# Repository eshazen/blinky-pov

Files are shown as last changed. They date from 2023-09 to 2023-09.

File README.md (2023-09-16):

# Blinky POV

This is a copy of designs from the EDF SVN for Blinky POV (persistence
of vision) toys for soldering training and outreach.

**AVR4** - Version 4 of thru-hole design using an ATTiny44A MCU.
This includes firmware and HTML blinky programming code

**BlinkyColorPOV** - Version using RGB LEDs.  Some issues with
soldering the 4-pin LEDs.  Probably overly-complex for a new project.

See https://github.com/eshazen/blinky-avr-smt for a newer version
based loosely on AVR4.

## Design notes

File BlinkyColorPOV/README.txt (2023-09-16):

This repository contains the documentation and firmware for the "Blinky Color POV"
gadget, which displays text in color when waved back and forth in the air.

Downloading is accomplished using a variation of the "Blinky POV" optical download
technique by Wayne&Layne.  See: http://www.wayneandlayne.com/projects/blinky/

Hardware  	       KiCAD PCB layout and gerber files
		       Hardware/gerber/blinky_color2.zip is latest fab package

Firmware/ColorText     Firmware for final version
		       Edit makefile as required for download cable, then
		       'make fuse' and 'make flash'

Programming	       Javascript download tool
		       use 'colortext.html', with on-screen documentation

myFont2c	       Contains 'fontExtract' tool which converts an X11 bitmap
		       font to javascript data

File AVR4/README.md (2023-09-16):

# blinky-pov
Blinky POV soldering projects

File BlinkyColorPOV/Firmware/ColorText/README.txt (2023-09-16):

First attempt at full version.
Character-based, ASCII codes 32-95 supported

Timing issues:

Optimized I2C for accel- 400kHz clock, read only one byte (X)
A read takes about 130us.  Could be interrupt driven?

Neopixel timing is 24 bits '1' is 1.5uS, '0' is 1.3uS.
So 1.5uS * 24 * 8 is about 300uS for an update of all 8 LEDs

Hand sweep of blinky is ~ 1Hz or 500ms per direction.
If we allow 20 characters at average with of 5 pixels, that's
100 pixels or 5ms per pixel.  Should work down to 1ms per pixel,
For total error less than 1/2 character (2 pixels) that's
2% of 5ms or 100us.  So pixel timing should be scheduled in 
100uS ticks.

Interrupts must be disabled during neopixel output, though
the timer can still run.

Timer setup for non-interrupt ops:
TCCR1A = $00
TCCR1B = $0x where x is $04 with prescale 1...5 for 1, 8, 64...1024

Proposed implementation:

Setup timer1 for 128uS counting (prescale=1024)

Measure time between zero-crossings (200-700ms or so)
Calculate pixel update period in 100us uinits.

100us loop:
  if time >= next_pixel:
    run_pixel_update
  if time >= next_accel:
    run_accel_update

----------------------------------------

Download protocol:

9 bit tokens
  0x55 0x1aa        (sync)
  <nchars>          (character count)
  <code> <code>..   (low 6 bits are character code, upper 3 are color)
  <checksum>        (such that sum of all = 0)

Character codes start with 0=ascii 32 (space), 1=ascii 33 "!" etc
through 63=ascii 95 (unused code)

Sent as DDR bit-stream as follows using blinking squares on monitor.
Maximum achievable rate with a typical browser/monitor seems to
be about 10 bits/s.

white    +----+    +----+    +----+    +----+    +----+    +----+    
CLOCK    |    |    |    |    |    |    |    |    |    |    |    | 
black----+    +----+    +----+    +----+    +----+    +----+    +--

white  +----+    +----+    +----+    +----+    +----+    +----+    
DATA   | 8  | 7  | 6  | 5  | 4  | 3  | 2  | 1  | 0  | 8  | 7  | 6  
black--+    +----+    +----+    +----+    +----+    +----+    +----

One thing to note is that since the transfer is DDR and the word
length is odd, that the first word's MSB is on a rising clock edge,
while next is on a falling clock edge etc.

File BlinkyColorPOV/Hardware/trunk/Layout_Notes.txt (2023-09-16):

10/24/17  Edits for 2017

* Stagger pins on LEDs for easier soldering
  with bigger pads/holes

Check on below, not sure all done

*  Polarity mark on IC1
*  SW2 holes too small
*  Move P1 up a bit
*  Fix light sensor wiring:  GND bottom, ADC to middle, now ADC is good
*  USART works Tx and Rx

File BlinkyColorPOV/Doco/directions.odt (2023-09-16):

Blinky Color POV Parts rev 2

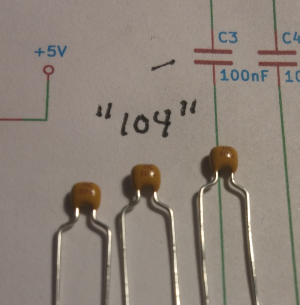
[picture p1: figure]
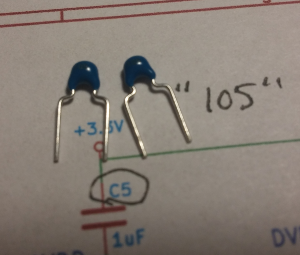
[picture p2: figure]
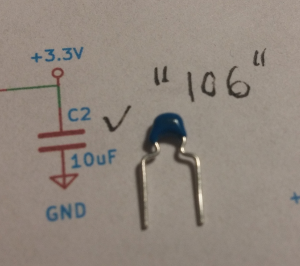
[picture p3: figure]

100nF Capacitor (C1, C3, C4, C6) | 1uF Capacitor( C5, C7, C8) marked “105” in tiny print Need 3 of these | 10uF Capacitor (C2) marked “106” in tiny print With a black dot

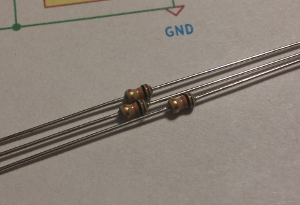
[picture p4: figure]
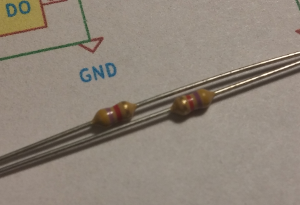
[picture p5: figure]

10k Resistor (R1, R4, R5) | 4.7k Resistor (R2, R3) | LED (D1-D8)

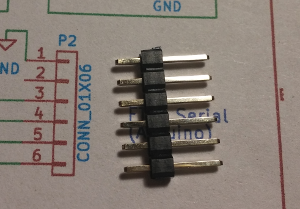
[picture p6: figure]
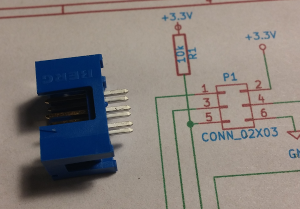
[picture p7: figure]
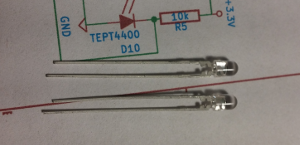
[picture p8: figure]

Connector (Optional) P2 | Connector (Optional) P1 | Light sensors (D9, D10)

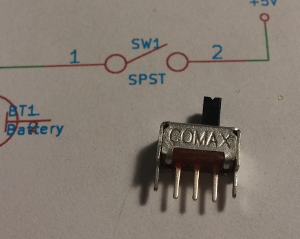
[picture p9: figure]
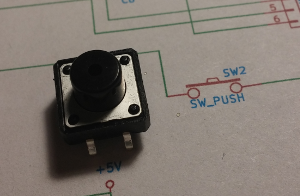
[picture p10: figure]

Switch (SW1) | Push button (SW2) | Voltage regulator (U1)

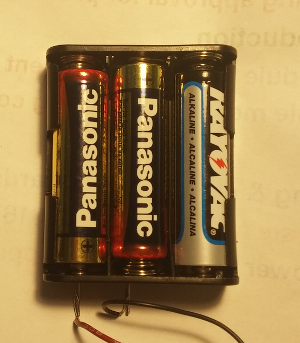
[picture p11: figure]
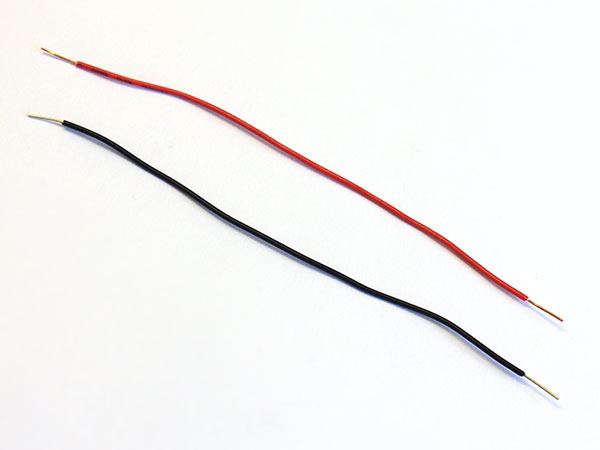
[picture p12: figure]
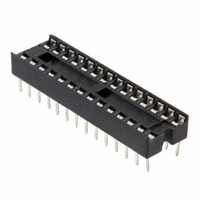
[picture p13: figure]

Battery Case | Red and Black Wires | IC Socket

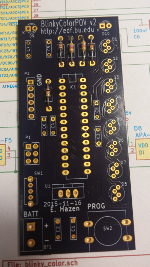
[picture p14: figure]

Circuit Board

# Directions.....

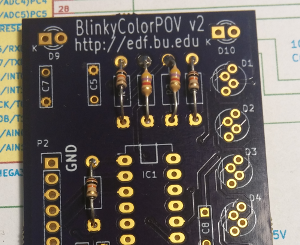
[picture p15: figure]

1. Solder in the resistors R2 and R3 are 4.7k Yellow, Violet, Red, Gold R1, R4 and R5 are 10k Brown, Black, Orange, Gold

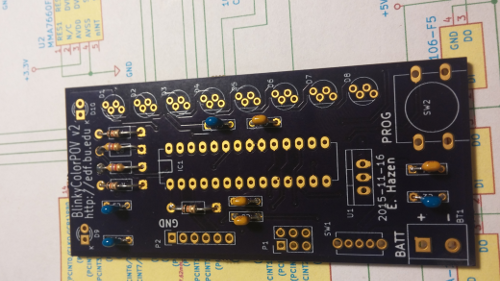
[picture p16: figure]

2. Solder in the capacitors C2 is 10uF “106” C5, C7, C8 are 1uF “105” C1, C3, C4, C6 are 0.1uF “104”

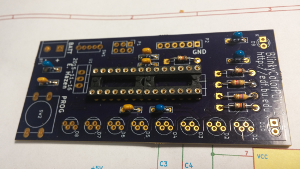
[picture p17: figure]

3. Solder in the IC socket IC1 Be sure the notch is the same way up as the mark on the board!

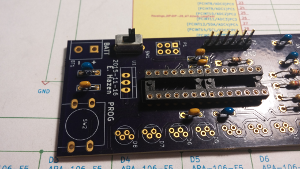
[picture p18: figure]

4. Solder in the power switch SW1

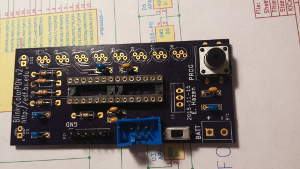
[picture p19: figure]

5. Solder in the Programming Button PROG

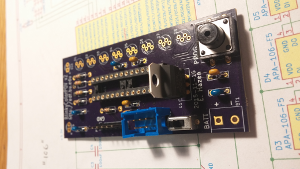
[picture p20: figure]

6. Solder in the voltage regulator U1 Make sure it goes the right way around, with the metal tab towards U2

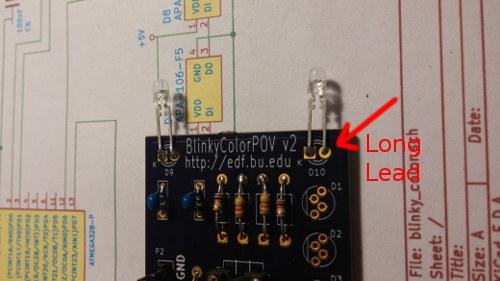
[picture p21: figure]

7. Solder in the light sensors They have to go the right way around The long lead goes in the round pad The short lead goes in the square pad Bend them so they stick out and are about the same length, as shown

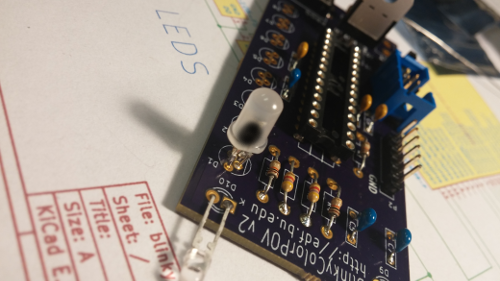
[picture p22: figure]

8. Solder in the LEDs These are tricky. They have 4 leads. The side with the black dot goes up towards the top of the board (where the light sensors are)

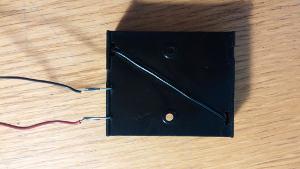
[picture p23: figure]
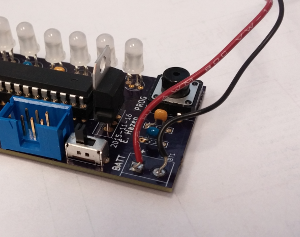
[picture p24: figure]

9. Attach the wires to the battery holder Solder the red and black wires to the battery holder as shown. Be sure the red wire is connected to the pin near the corner. Solder the other end of the wires into the circuit board. The red wire goes into the “+”hole

You're done!

Inspect your work carefully, and get your helper to check it out, too.

Then, go ask for batteries and a microcontroller and you're ready to try out your BlinkyColorPOV!

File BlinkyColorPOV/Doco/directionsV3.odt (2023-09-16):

Blinky Color POV Parts rev 3 Dec 2016

For programming, go to: http://edf.bu.edu/pov


← SIP socket (1)

Accelerometer →

(1)


1. Solder in the resistors R1, R2, R3, R4, R5 Bend the leads over on the back, solder and cut off the extra wire.


2. Solder in the capacitors C8 is blue The others (C1, C2, C3, C4, C6) are yellow


3. Solder in the IC socket IC1 - bend over two corner pins on the back to keep it from falling out while you solder it. | Be sure the notch is the same way up as the mark on the board!


4. Solder in the power switch SW1


5. Solder in the Programming Button PROG 6. Solder in the voltage regulator (be sure to put it the right way around) U1


7. Solder in the light sensors (D9, D10) Bend them so they stick out and are about the same length, as shown | They have to go the right way around The long lead goes in the round pad The short lead goes in the square pad


8. Solder in the LEDs (D1...D8) These are tricky. They have 4 leads, and they have to go the right way around. Bend the leads apart, and be very careful when you solder them not to make any “solder bridges” between the pins.


9. Install the SIP socket P3 – This goes on the front next to the resistors. | 9a. Plug the accelerometer board into the socket


10. Install the battery holder It goes on the back as shown. The two wires go in the holes marked Batt + and -. Solder the wires on the front where they poke thru the board.

You're done!

Inspect your work carefully, and get your helper to check it out, too.

Then, go ask for batteries and a microcontroller and you're ready to try out your BlinkyColorPOV!

For programming, go to: http://edf.bu.edu/pov

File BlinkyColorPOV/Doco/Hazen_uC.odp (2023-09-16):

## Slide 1


Welcome To

Science Solstice

2016

At the

Electronics

Design

Facility

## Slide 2


What is it? A “BlinkyPOV”

POV means

“persistence of vision”


As you wave the MiniPOV, the LEDs blink

out a message by turning on in a pattern.

Your eye sees the message because the

image of the LEDs “persists” (stays) for a while

in your eye

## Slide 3

How does it work?


The black thing with all the legs

is a tiny computer called

a microcontroller

They are programmed in

a language called C

They are used in lots of

things around your house

(microwave, stereo, TV...)

Other parts are needed too...


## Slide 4

Parts, Parts, Parts!


LED (light-emitting diode)

Lights up in response to electric current


Resistor – limits the amount of

electric current in a circuit

Microcontroller – tiny computer

Each leg (pin) can be controlled

by a program in C


Switch – allows electricity to flow

when pressed

Capacitor – stores electricity

(like a battery, but for shorter times)

## How Do We Design It?

- Draw a wiring diagram (schematic)
- Draw a layout
- Send the design to a company to make the printed circuit board
- Solder in the parts (you get to do this!)
- Program it (you get to do this too)
- Test it

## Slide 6


This is the

schematic

(wiring diagram)

LEDs

The red symbols

are parts

The green lines

show how the

parts are

connected

Batteries

Microcontroller

Resistors

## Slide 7


Everything is soldered

into a printed circuit board

The squiggly lines are printed

in copper on the board like wires

... they connect together the

parts to make an electric circuit

## Soldering

- Soldering is the joining of metal objects together. A filler metal (“solder”) is melted and flowed into the joint.
- Soldering was practiced in ancient Egypt at least 7000 years ago
- Soldering is used to attach electronic components to a board, and also for jewelery and other applications


## Soldering Safety

- The iron gets hot! Don't burn yourself. Careful not to splash solder
- Solder is made of lead, which is poisonous Wash your hands when you are done; don't eat or drink while soldering
- Snipped component leads fly at high speeds Close your eyes or cover board with your hands

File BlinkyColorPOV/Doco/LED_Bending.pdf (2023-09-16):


Long 2 leads

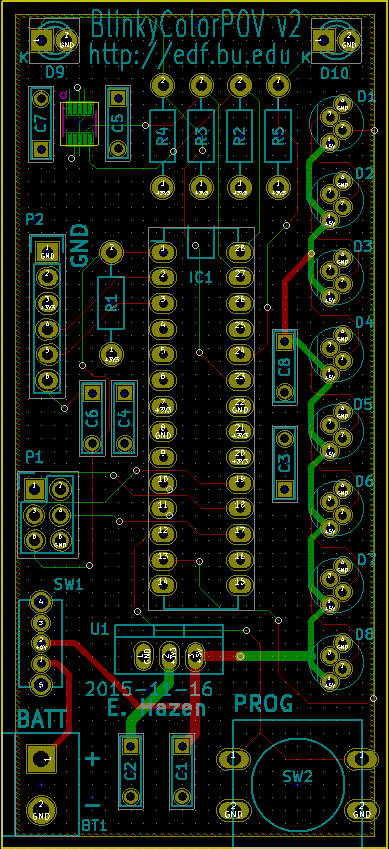
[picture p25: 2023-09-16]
BlinkyColorPOV/Hardware/branches/2017/layout_screenshot.png

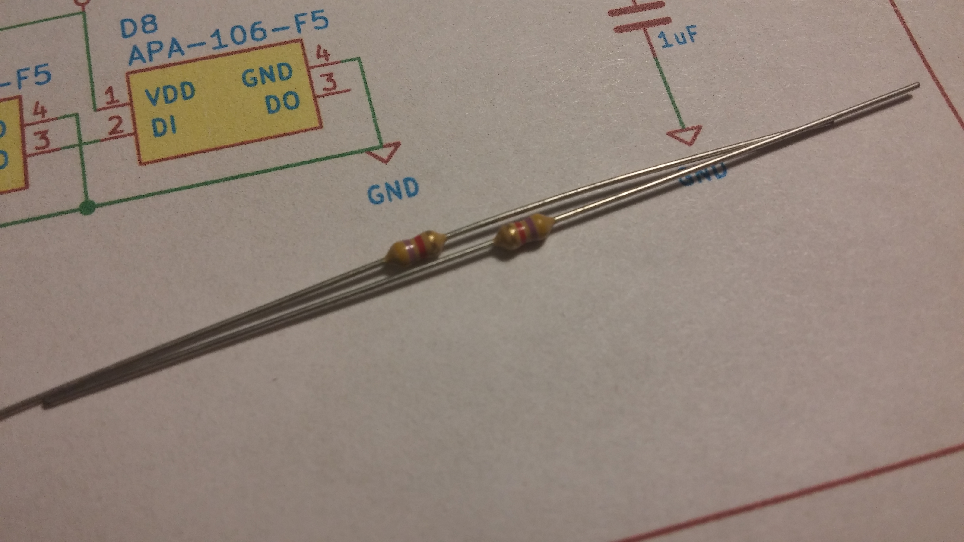
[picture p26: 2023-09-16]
BlinkyColorPOV/pix/2015-11-30 16.27.35.jpg

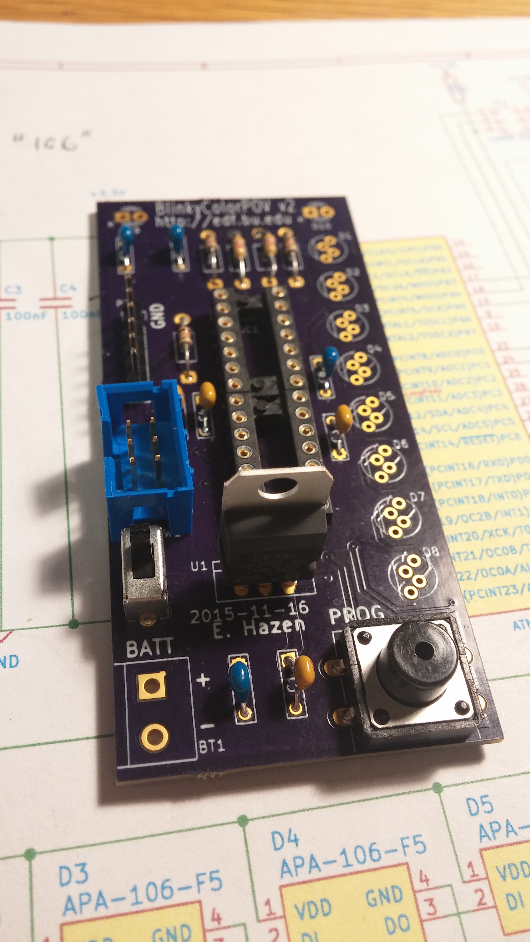
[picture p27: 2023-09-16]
BlinkyColorPOV/pix/2015-11-30 17.03.38.jpg

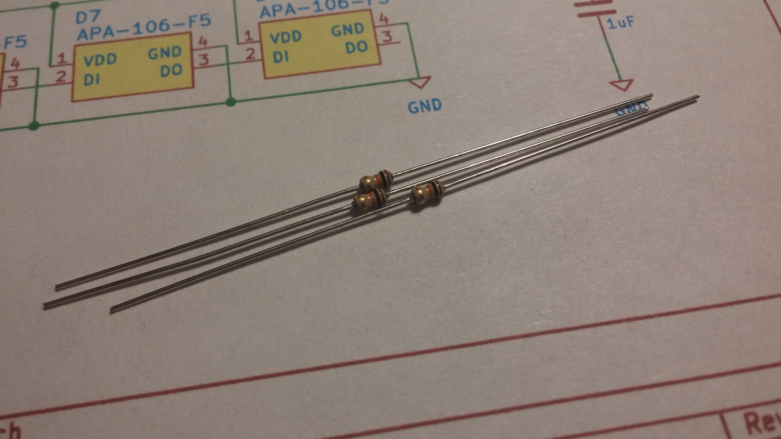
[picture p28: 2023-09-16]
BlinkyColorPOV/pix/2015-11-30 16.28.10.jpg

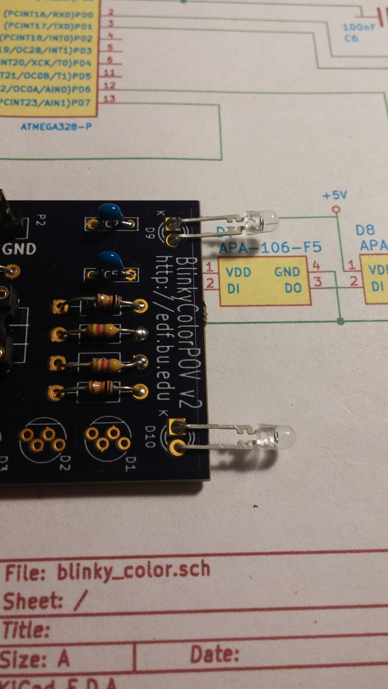
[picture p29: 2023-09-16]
BlinkyColorPOV/pix/2015-11-30 17.12.10.jpg

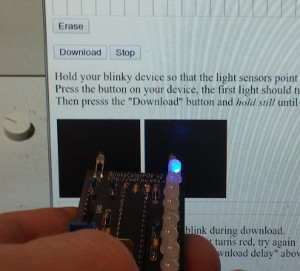
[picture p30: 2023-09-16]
BlinkyColorPOV/Programming/download.jpg

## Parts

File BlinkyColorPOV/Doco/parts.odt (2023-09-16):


C1, C3, C4 (3) | Capacitor, 100nF


C2 (1) | Capacitor, 10uF


C5, C7, C8 (3) | Capacitor, 1uF


R1, R4, R5 (3) | Resistor, 10k Brown, Black, Orange, Gold


R2, R3 (2) | Resistor, 4.7k Yellow, Violet, Red, Gold

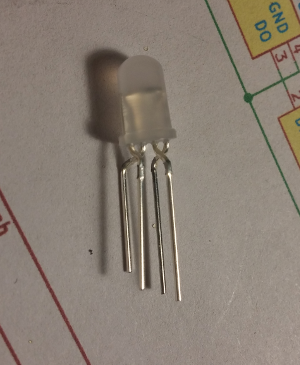
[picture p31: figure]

D1-D8 | RGB Addressable LED
IC1 | IC Socket, 28 pins | MISSING PHOTO
BT1 | Battery holder 3x AA | MISSING PHOTO


P2 | Connector straight 6 pin


P1 | Pin header 2x6


D9, D10 | Light Sensor


SW1 | Switch


SW2 | Push button switch

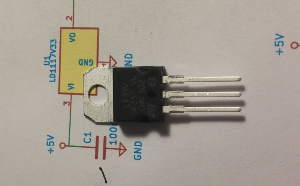
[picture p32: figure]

U1 | Voltage Regulator

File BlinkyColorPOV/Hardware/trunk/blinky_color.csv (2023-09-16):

Reference | Value | Footprint | Datasheet | CatNo
IC1 | ATMEGA328-P | Housings_DIP:DIP-28_W7.62mm_LongPads
D1 | APA-106-F5 | Connect:bornier4 |  | COM-12986 (pk5)
D2 | APA-106-F5 | Connect:bornier4 |  | COM-12986 (pk5)
D3 | APA-106-F5 | Connect:bornier4 |  | COM-12986 (pk5)
D4 | APA-106-F5 | Connect:bornier4 |  | COM-12986 (pk5)
D5 | APA-106-F5 | Connect:bornier4 |  | COM-12986 (pk5)
D6 | APA-106-F5 | Connect:bornier4 |  | COM-12986 (pk5)
D7 | APA-106-F5 | Connect:bornier4 |  | COM-12986 (pk5)
D8 | APA-106-F5 | Connect:bornier4 |  | COM-12986 (pk5)
U2 | MMA7660FC | Housings_SSOP:MSOP-10_3x3mm_Pitch0.5mm
R2 | 4.7k | Resistors_ThroughHole:Resistor_Horizontal_RM10mm
R3 | 4.7k | Resistors_ThroughHole:Resistor_Horizontal_RM10mm
C4 | 100nF | Capacitors_ThroughHole:C_Rect_L7_W2_P5 |  | BC2665CT-ND
C3 | 100nF | Capacitors_ThroughHole:C_Rect_L7_W2_P5 |  | BC2665CT-ND
P1 | CONN_02X03 | Pin_Headers:Pin_Header_Straight_2x03 |  | 609-2845-ND
R1 | 10k | Resistors_ThroughHole:Resistor_Horizontal_RM10mm
D9 | TEPT4400 | Diodes_ThroughHole:Diode_P600_Vertical_AnodeUp |  | 751-1057-ND
D10 | TEPT4400 | Diodes_ThroughHole:Diode_P600_Vertical_AnodeUp |  | 751-1057-ND
R5 | 10k | Resistors_ThroughHole:Resistor_Horizontal_RM10mm
R4 | 10k | Resistors_ThroughHole:Resistor_Horizontal_RM10mm
SW2 | SW_PUSH | Buttons_Switches_ThroughHole:SW_PUSH-12mm |  | CKN9140-ND
BT1 | Battery | Connect:bornier2
SW1 | SPST | Buttons_Switches_ThroughHole:SW_Micro_SPST |  | CKN10397-ND
U1 | LD1117V33 | TO_SOT_Packages_THT:TO-220_Neutral123_Vertical |  | 497-1491-5-ND
C2 | 10uF | Capacitors_ThroughHole:C_Rect_L7_W2_P5 |  | 445-8592-ND
C1 | 100nF | Capacitors_ThroughHole:C_Rect_L7_W2_P5 |  | BC2665CT-ND
P2 | CONN_01X06 | Pin_Headers:Pin_Header_Straight_1x06 |  | S1011EC-06-ND
C5 | 1uF | Capacitors_ThroughHole:C_Rect_L7_W2_P5 |  | 445-8591-ND
C7 | 1uF | Capacitors_ThroughHole:C_Rect_L7_W2_P5 |  | 445-8591-ND
C8 | 1uF | Capacitors_ThroughHole:C_Rect_L7_W2_P5 |  | 445-8591-ND

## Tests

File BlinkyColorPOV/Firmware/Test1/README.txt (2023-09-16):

Initial blinky for BlinkyColorPOV
Test with LED wired to PB0 and it works!

Button input works.

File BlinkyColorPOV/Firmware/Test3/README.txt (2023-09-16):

Read light sensors and output to neopixels and UART
Have to rewire light sensors, then OK

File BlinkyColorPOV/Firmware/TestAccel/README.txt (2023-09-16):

Test readout tof MMA7660FC accelerometer
works ok

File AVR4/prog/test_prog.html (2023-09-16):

# Blinky POV Programming

Message:
Available characters: 0-9, A-Z, !, ?, &, \',\', and \'.\'.



Progress: Canceled

| | Delay (ms):

Data

Clock

Programming Instructions: Enter your message in the "Message" box.

- Hold board up to monitor as shown, with the LEDs up. The light sensors must point at the two squares marked "Clock" and "Data".
- Press the white button on the board. The top LED (D8) should come on and then go off.
- Click the "Go" button above. The squares will flash, and the top LED on your board should flash as the message is downloaded.



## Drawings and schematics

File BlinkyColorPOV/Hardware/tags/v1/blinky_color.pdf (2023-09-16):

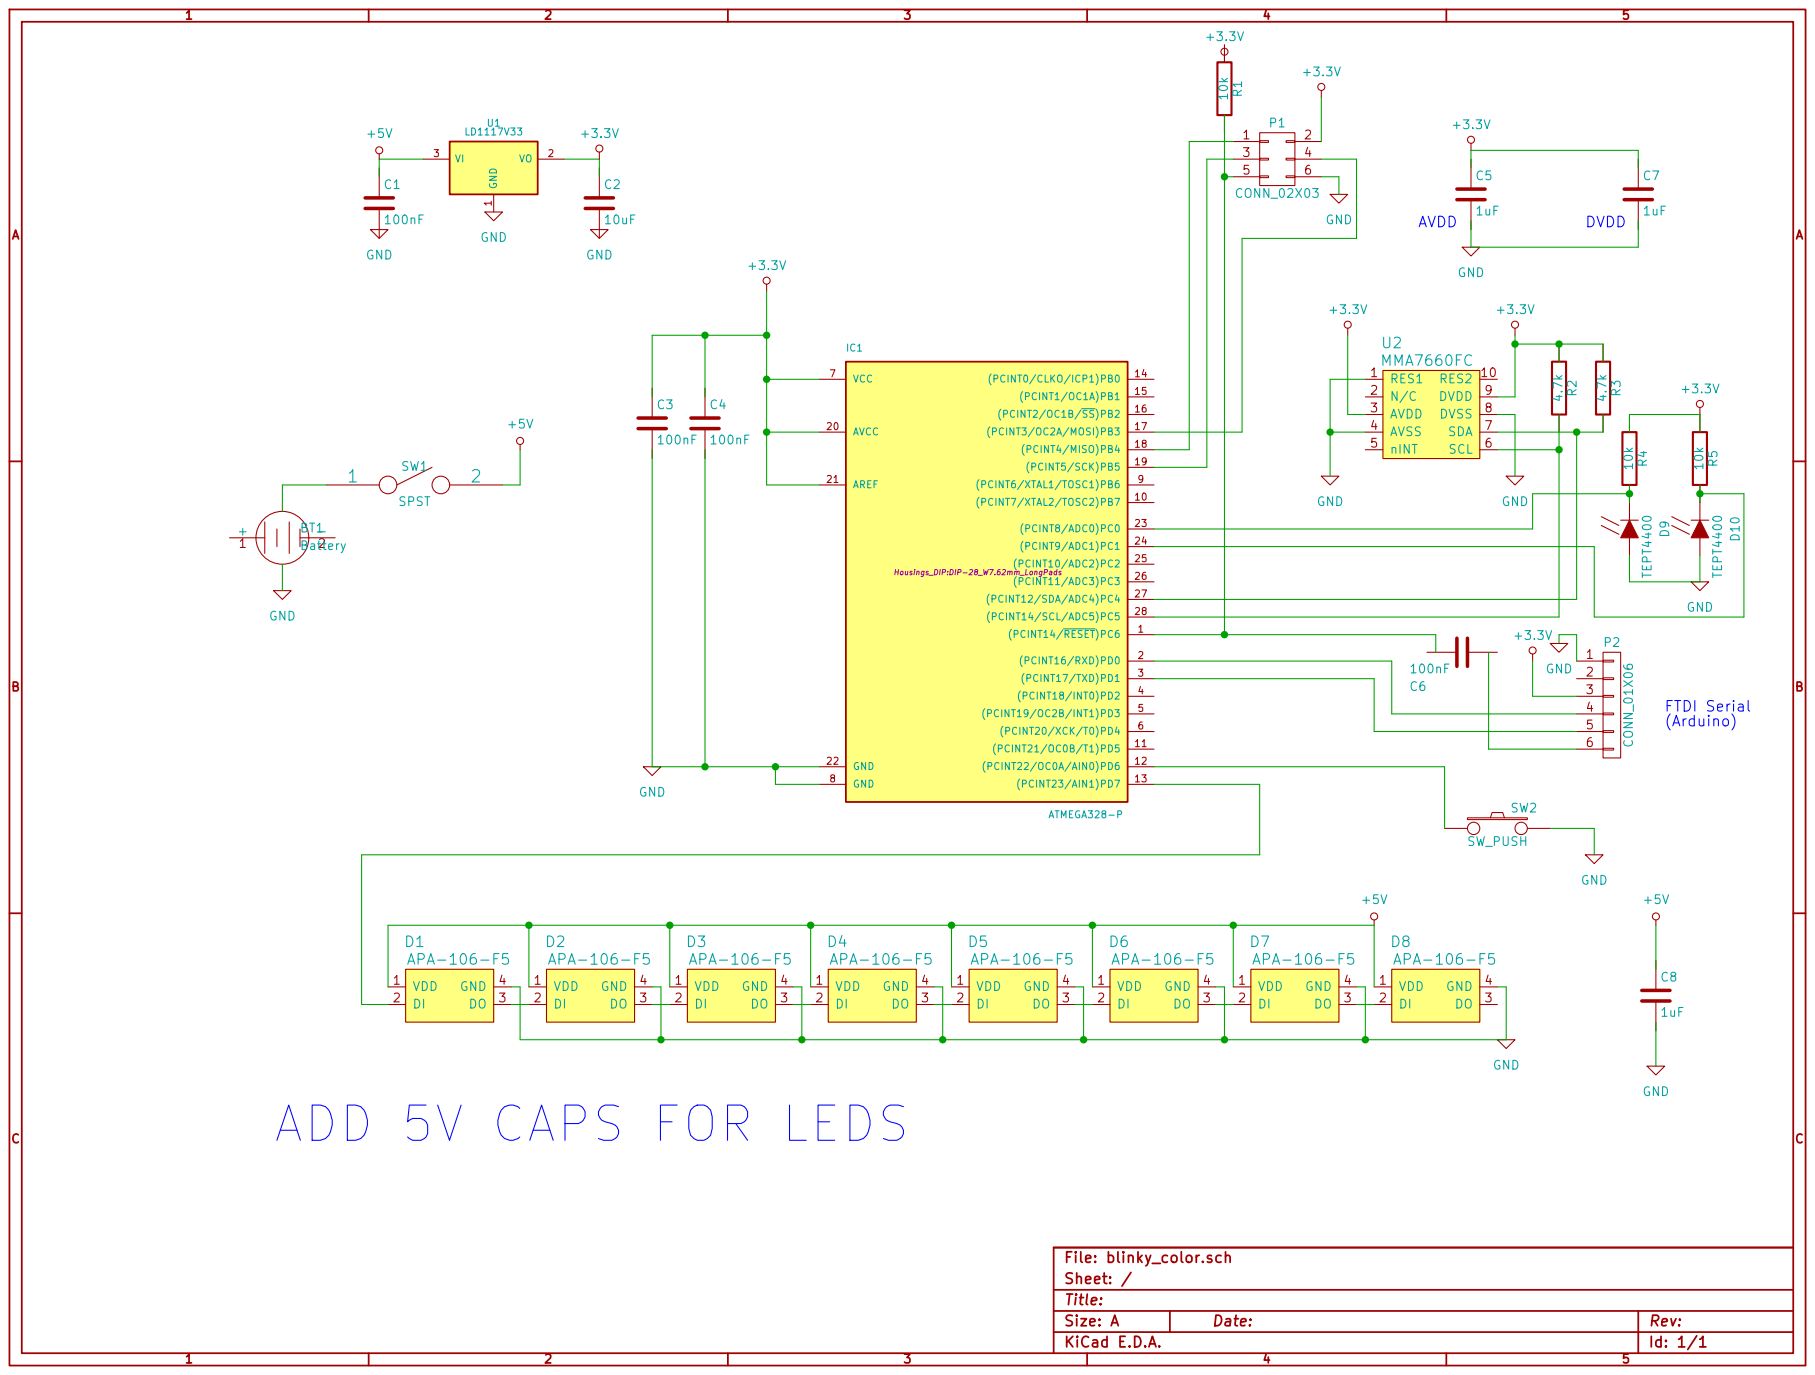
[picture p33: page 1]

+5V ADD 5V CAPS FOR LEDS

Id: 1/1 Title: File: blinky_color.sch
Sheet: /

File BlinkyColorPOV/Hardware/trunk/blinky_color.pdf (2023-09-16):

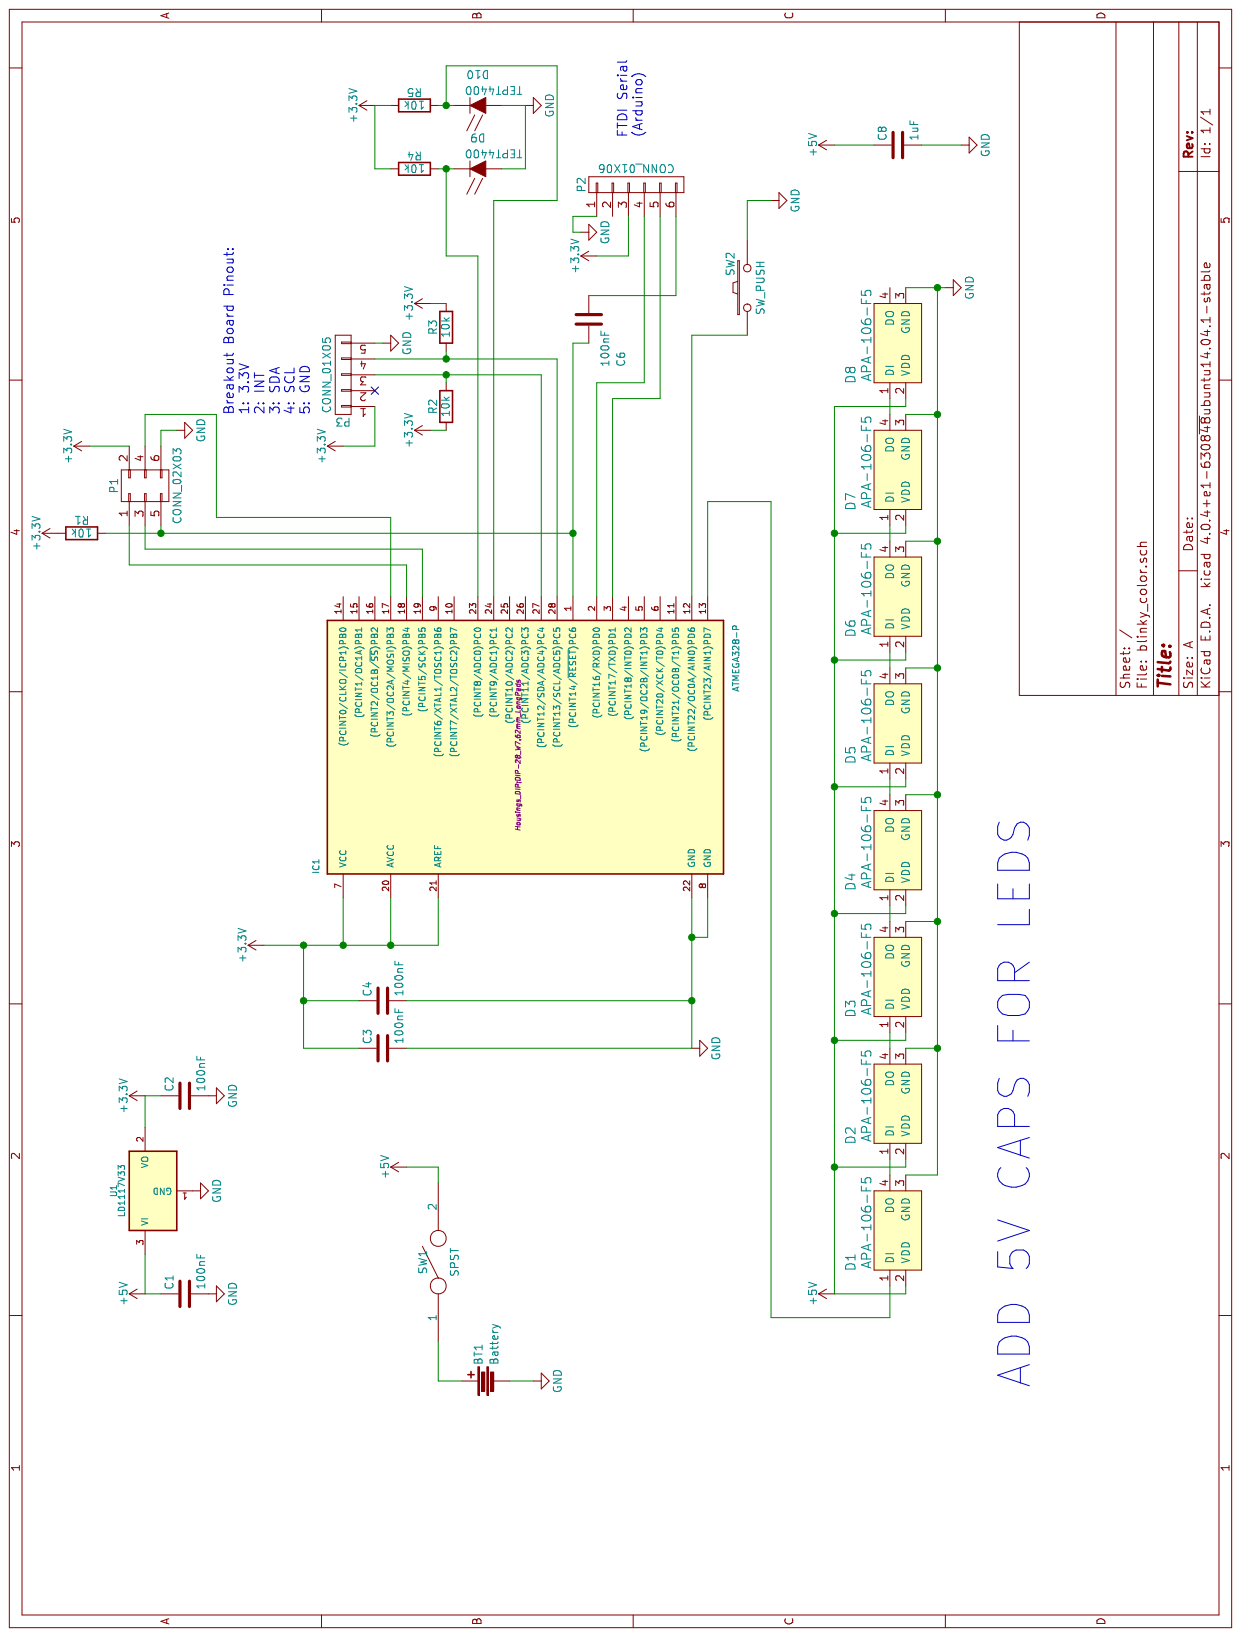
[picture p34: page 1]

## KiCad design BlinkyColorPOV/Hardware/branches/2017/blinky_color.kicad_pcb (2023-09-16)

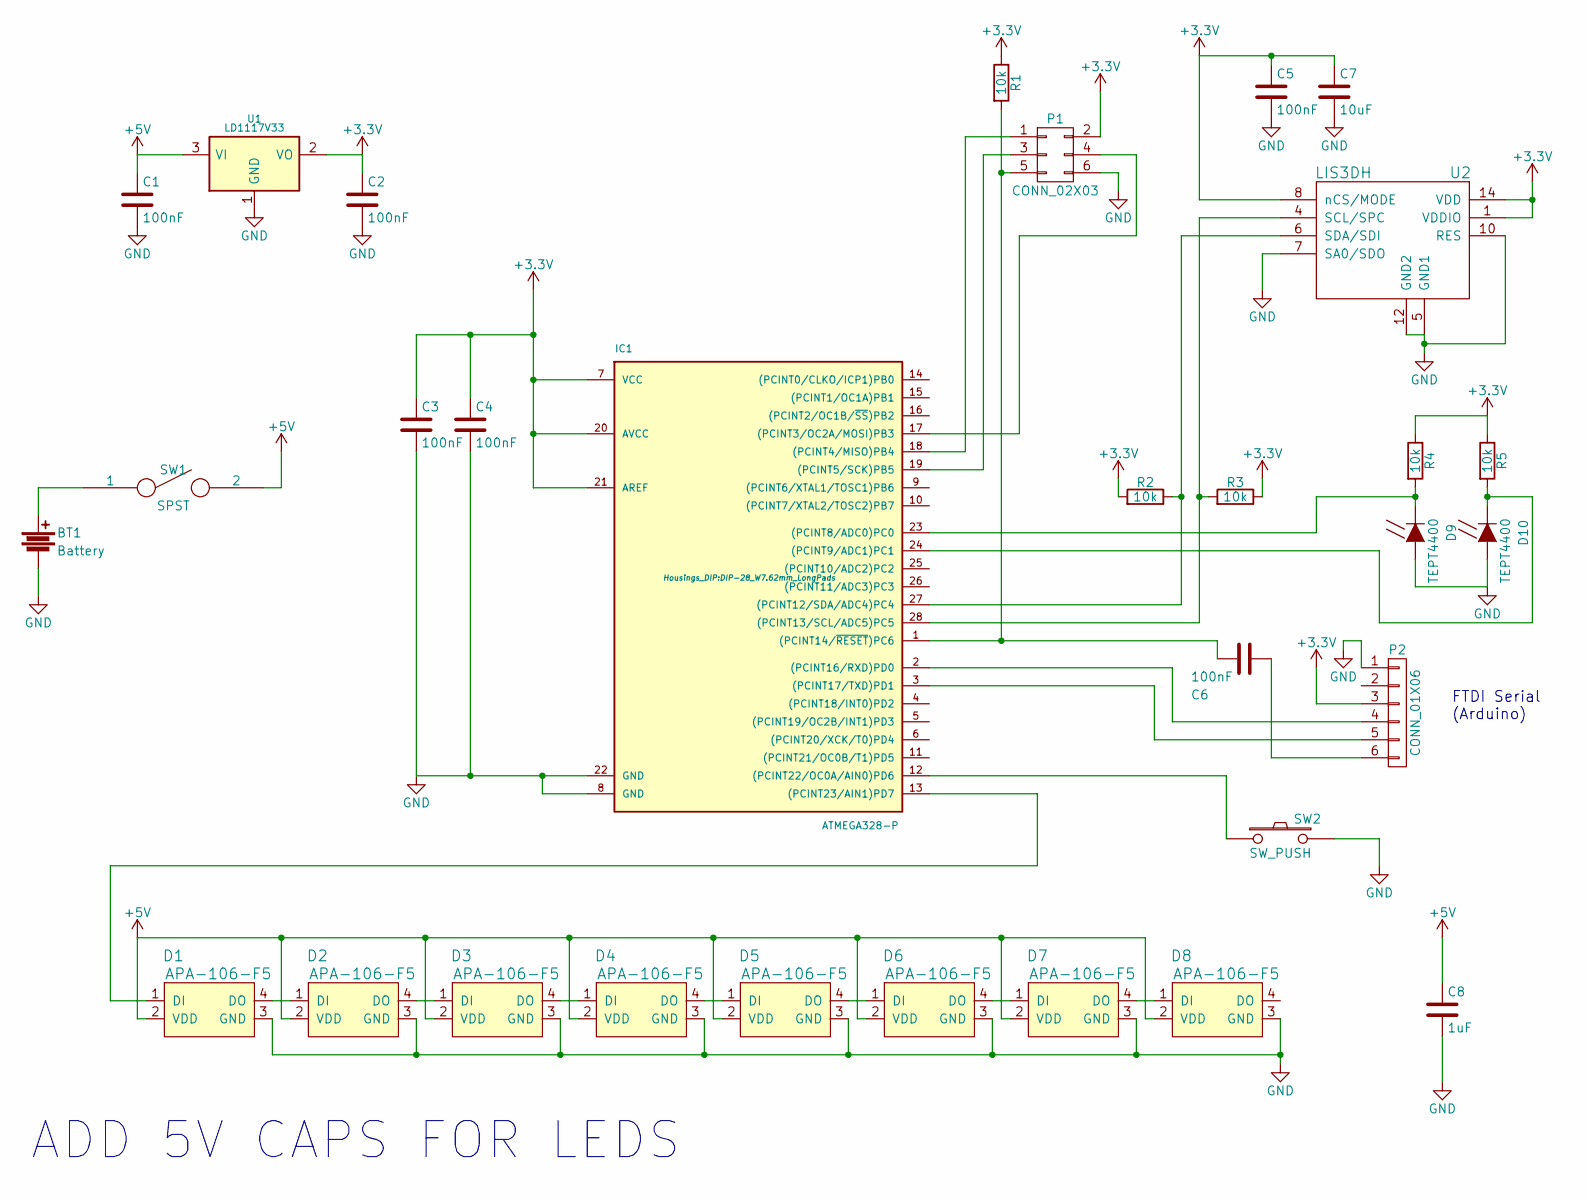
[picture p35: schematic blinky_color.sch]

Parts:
BT1: Battery; AAA_batterypack
C1, C5: 100nF; C_Rect_L7.0mm_W2.0mm_P5.00mm
C2, C3, C4, C6: 100nF; C_Rect_L7_W2_P5
C7: 10uF; C_Rect_L7.0mm_W2.0mm_P5.00mm
C8: 1uF; C_Rect_L7_W2_P5
D1, D2, D3, D4, D5, D6, D7, D8: APA-106-F5; bornier4
D9, D10: TEPT4400; Diode_P600_Vertical_AnodeUp
IC1: ATMEGA328-P; DIP-28_W7.62mm_LongPads
P1: CONN_02X03; Pin_Header_Straight_2x03
P2: CONN_01X06; Pin_Header_Straight_1x06
R1, R2, R3, R4, R5: 10k; Resistor_Horizontal_RM10mm
SW1: SPST; SW_Micro_SPST
SW2: SW_PUSH; SW_PUSH-12mm
U1: LD1117V33; TO-220_Neutral123_Vertical
U2: LIS3DH; lga16

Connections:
+3V3: C2.1, C3.1, C4.1, C5.1, C7.1, IC1.7 (VCC), IC1.20 (AVCC), IC1.21 (AREF), P1.2, P2.3, R1.1, R2.2, R3.1, R4.1, R5.1, U1.2 (VO), U2.1 (VDDIO), U2.8 (nCS/MODE), U2.14 (VDD)
+5V: C1.1, C8.1, D1.2 (VDD), D2.2 (VDD), D3.2 (VDD), D4.2 (VDD), D5.2 (VDD), D6.2 (VDD), D7.2 (VDD), D8.2 (VDD), SW1.2, U1.3 (VI)
GND: BT1.2, C1.2, C2.2, C3.2, C4.2, C5.2, C7.2, C8.2, D1.3 (GND), D2.3 (GND), D3.3 (GND), D4.3 (GND), D5.3 (GND), D6.3 (GND), D7.3 (GND), D8.3 (GND), D9.2 (A), D10.2 (A), IC1.8 (GND), IC1.22 (GND), P1.6, P2.1, SW2.2, U1.1 (GND), U2.5 (GND1), U2.7 (SA0/SDO), U2.10 (RES), U2.12 (GND2)
unnamed: BT1.1, SW1.1
unnamed: C6.1, P2.6
unnamed: C6.2, IC1.1 ((PCINT14/~RESET~)PC6), P1.5, R1.2
unnamed: D1.1 (DI), IC1.13 ((PCINT23/AIN1)PD7)
unnamed: D1.4 (DO), D2.1 (DI)
unnamed: D2.4 (DO), D3.1 (DI)
unnamed: D3.4 (DO), D4.1 (DI)
unnamed: D4.4 (DO), D5.1 (DI)
unnamed: D5.4 (DO), D6.1 (DI)
unnamed: D6.4 (DO), D7.1 (DI)
unnamed: D7.4 (DO), D8.1 (DI)
unnamed: D9.1 (K), IC1.23 ((PCINT8/ADC0)PC0), R4.2
unnamed: D10.1 (K), IC1.24 ((PCINT9/ADC1)PC1), R5.2
unnamed: IC1.2 ((PCINT16/RXD)PD0), P2.4
unnamed: IC1.3 ((PCINT17/TXD)PD1), P2.5
unnamed: IC1.12 ((PCINT22/OC0A/AIN0)PD6), SW2.1
unnamed: IC1.17 ((PCINT3/OC2A/MOSI)PB3), P1.4
unnamed: IC1.18 ((PCINT4/MISO)PB4), P1.1
unnamed: IC1.19 ((PCINT5/SCK)PB5), P1.3
unnamed: IC1.27 ((PCINT12/SDA/ADC4)PC4), R2.1, U2.6 (SDA/SDI)
unnamed: IC1.28 ((PCINT13/SCL/ADC5)PC5), R3.2, U2.4 (SCL/SPC)

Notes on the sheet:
FTDI Serial (Arduino)
ADD 5V CAPS FOR LEDS

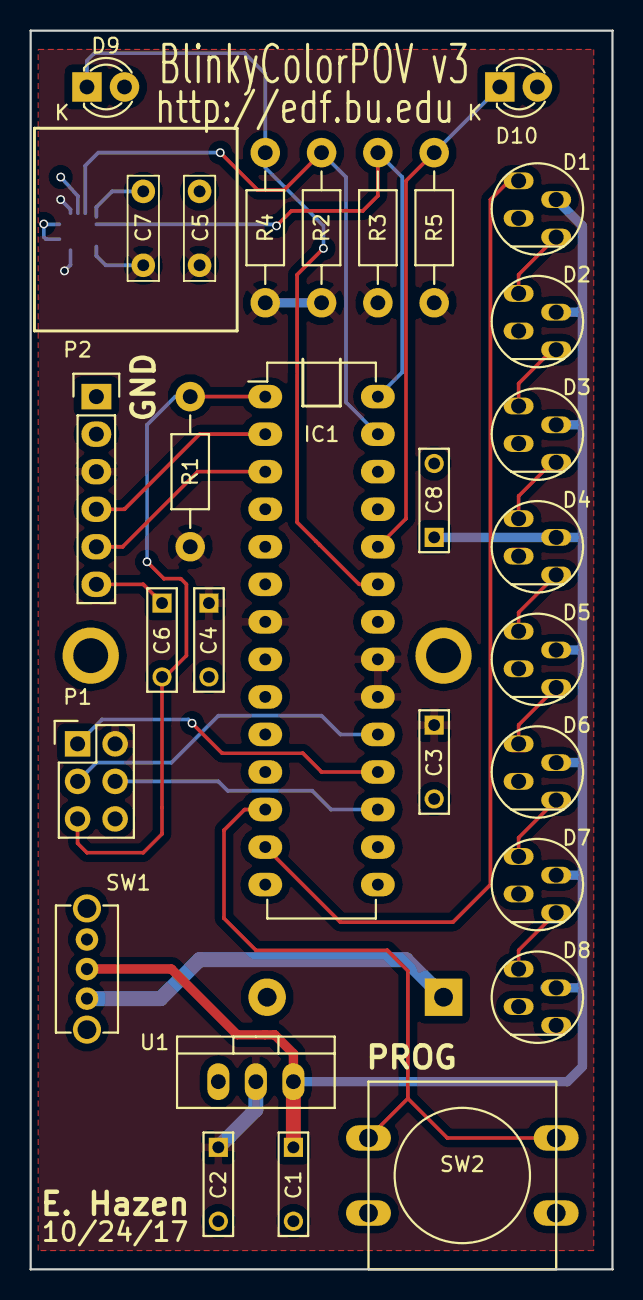
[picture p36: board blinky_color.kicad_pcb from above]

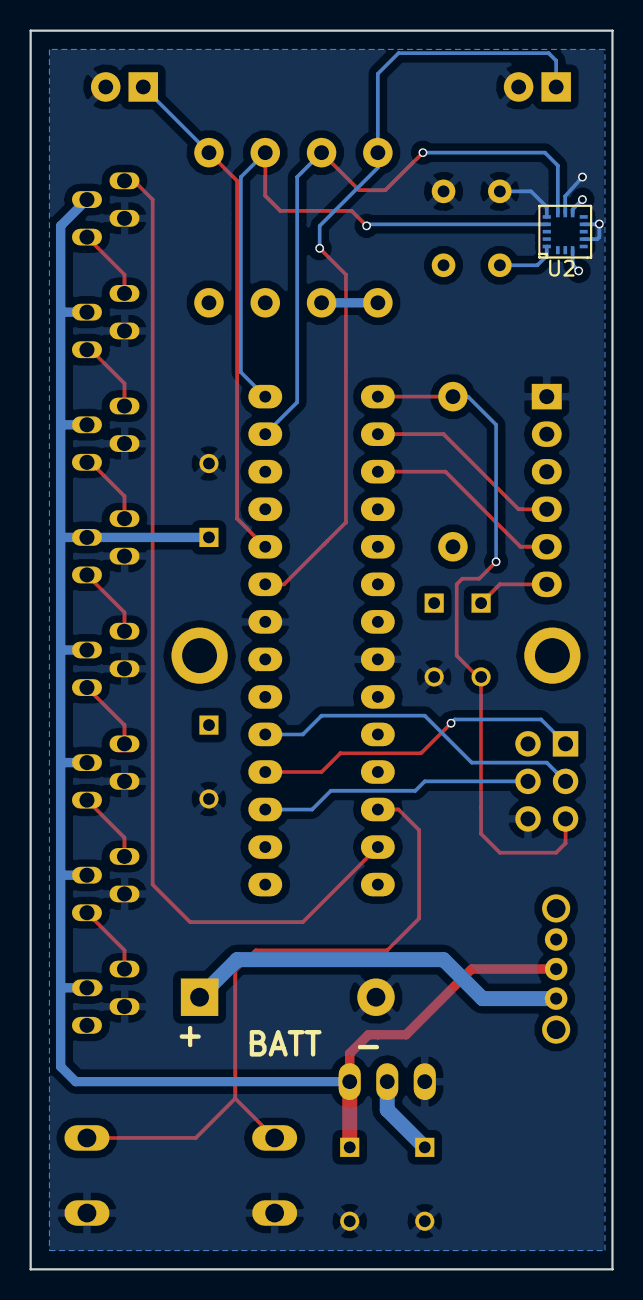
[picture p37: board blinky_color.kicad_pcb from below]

Board: 2 copper layers, 39.4 x 83.8 mm, 31 parts (2 on the bottom side), 24 nets.

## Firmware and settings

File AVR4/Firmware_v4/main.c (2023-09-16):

/*
 * main.c - BlinkyPov/AVR downloader
 *
 * Mods:
 * 2012-11-25, esh -- initial working version.  Supports download of one font-based
 * message to EEPROM.  Displays message on power-up, waits for button press.
 * 2012-11-26, esh -- port for Rev2 board
 *
 * TODO:
 * Implement pixel-based messages, multiple messages
 */

#define REV2

#define USE_EEPROM

// #define USE_UART

#include <avr/io.h>
#include <util/delay.h>
#include <avr/eeprom.h>
#include <string.h>

#include "font_table.h"
#define FONT_WIDTH 5	/* bytes per character in font */

#define LED_PORTA 0
#define LED_PORTB 1

// LED pin assignments
const uint8_t led_port_code[] PROGMEM = {
#ifdef REV2
  // these are valid for Rev4 layout for 2014
  LED_PORTA, 0,
  LED_PORTA, 1,
  LED_PORTA, 2,
  LED_PORTA, 3,
  LED_PORTA, 7,
  LED_PORTB, 0,
  LED_PORTB, 1,
  LED_PORTB, 2
#else
  LED_PORTA, 0,
  LED_PORTA, 1,
  LED_PORTA, 2,
  LED_PORTA, 3,
  LED_PORTA, 4,
  LED_PORTA, 5,
  LED_PORTB, 3,
  LED_PORTB, 2
#endif
};

#define led_bit(n) (pgm_read_byte(&(led_port_code[((n)<<1)+1])))
#define led_port(n) (pgm_read_byte(&(led_port_code[((n)<<1)])))

static void inline setup_led_ports()
{
  uint8_t i;
  for( i=0; i<8; i++) {
    if( led_port(i) == LED_PORTA)
      DDRA |= _BV(led_bit(i));
    else
      DDRB |= _BV(led_bit(i));
  }
}

// create masks for ports A/B for LEDs specified
// PORT A = low byte
// PORT B = high byte
static uint16_t led_mask( uint8_t leds)
{
  uint16_t v = 0;
  uint8_t i;
  uint8_t b = 1;

  for( i=0; i<8; i++) {
    if( leds & b) {
      if( led_port(i) == LED_PORTA)
	v |= _BV(led_bit(i));
      else
	v |= (_BV(led_bit(i)) << 8);
    }
    b <<= 1;
  }
  return v;
}

// toggle LEDs per mask
static void led_flip( uint8_t flip_mask)
{
  uint16_t v = led_mask( flip_mask);
  PORTA ^= (v & 0xff);
  PORTB ^= ((v>>8) & 0xff);
}

// turn on LEDs per mask
static void led_on( uint8_t on_mask)
{
  uint16_t v = led_mask( on_mask);
  PORTA |= (v & 0xff);
  PORTB |= ((v>>8) & 0xff);
}

// turn off LEDs per mask
static void led_off( uint8_t off_mask)
{
  uint16_t v = led_mask( off_mask);
  PORTA &= ~(v & 0xff);
  PORTB &= ~((v>>8) & 0xff);
}

// set LEDs per mask
static void led_set( uint8_t set_mask)
{
  led_off( 0xff);
  led_on( set_mask);
}




#ifdef USE_UART
#ifdef REV2
#define UART_PORT PORTA
#define UART_DDR DDRA
#define UART_TX_BIT _BV(5)
#else
#define UART_PORT PORTB
#define UART_DDR DDRB
#define UART_TX_BIT _BV(1)
#endif
#endif

#ifdef REV2
// ok for Rev4 layout
#define SW_PORT PORTA
#define SW_PIN PINA
#define SW_BIT 5
#else
#define SW_PORT PORTB
#define SW_PIN PINB
#define SW_BIT 0
#endif
#define SW_MASK _BV(SW_BIT)

#ifdef REV2
// ok for Rev4 layout
#define ADC_DATA 4
#define ADC_CLK 6
#else
#define ADC_DATA 6
#define ADC_CLK 7
#endif

#define CLK_VAL 1
#define DATA_VAL 2

// buffer for intel hex records (size 16)
#define BUFSIZ 24
static uint8_t ihex[BUFSIZ];

// buffer for EEPROM image
#define EEBUFSIZ 128
static uint8_t eebuf[EEBUFSIZ];

static uint8_t eep_nd;

// offsets of things in the hex record
#define IHEX_LEN 0
#define IHEX_ADDR 1
#define IHEX_TYPE 3
#define IHEX_DATA 4

// number of bytes in latest hex record
static uint8_t ihex_nd;

// address of latest hex record
static uint16_t ihex_addr;

// number of ADC samples to average
#define NAV 30

// logic threshold in ADC units (30 ~ 100mV)
#define THR 30

// variables for blinky receiver
static int16_t base_d, base_c;
static int32_t sum_d, sum_c;

// loop variable
static uint16_t k;
static int16_t a;


// flag:  button pressed, do reset
static uint8_t do_reset;

// global mode
static uint8_t mode;

#define MODE_BLINKY 0
#define MODE_LOAD 1



#ifdef USE_UART
// send a character to UART at 9600 baud using software delay
#define BAUD_DELAY_FUDGE 10
#define BAUD_DELAY_US ((1000000/9600)-BAUD_DELAY_FUDGE)

static void inline send_uart_bit( uint8_t b)
{
  if( b)
    UART_PORT |= UART_TX_BIT;
  else
    UART_PORT &= ~UART_TX_BIT;
  _delay_us( BAUD_DELAY_US);
}

// send byte to UART
static void uart_putc( uint8_t c)
{
  send_uart_bit( 0);		/* start bit */
  send_uart_bit( c & 1);
  send_uart_bit( c & 2);
  send_uart_bit( c & 4);
  send_uart_bit( c & 8);
  send_uart_bit( c & 0x10);
  send_uart_bit( c & 0x20);
  send_uart_bit( c & 0x40);
  send_uart_bit( c & 0x80);
  send_uart_bit( 1);		/* stop bit */
}

// convert nibble to hex
#define nibble_to_hex(n) ((n)>9?((n)+('A'-10)):((n)+'0'))

// send hex byte to UART
static void uart_hex2( uint8_t c)
{
  uart_putc( nibble_to_hex( (c>>4)&0xf));
  uart_putc( nibble_to_hex( c & 0xf));
}

// send hex word to UART
static void uart_hex4( uint16_t w) {
  uart_hex2( w>>8);
  uart_hex2( w);
}

// send newline sequence
static void inline crlf()
{
  uart_putc( 0x0d);
  uart_putc( 0x0a);
}
#endif

/*
 * Do all the startup-time peripheral initializations.
 */
static void ioinit(void)
{
  setup_led_ports();
#ifdef USE_UART
  UART_DDR |= UART_TX_BIT;
#endif
  SW_PORT |= SW_MASK;		/* pull-up on switch */
  ADCSRA |= _BV(ADEN);		/* enable ADC, default settings */
  //  ADCSRB |= _BV(ADLAR);		/* left adjust result */
  ADMUX = 7;
}



uint16_t read_adc( uint8_t ch)
{
  uint8_t lo, hi;

  ADMUX = ch;
  ADCSRA |= _BV(ADSC);
  loop_until_bit_is_clear( ADCSRA, ADSC);
  lo = ADCL;
  hi = ADCH;
  
  return( (hi<<8) | lo);
}


// sample the light sensor once (with averaging)
// return bit 0 = clk state  bit 1 = data state
uint8_t sample_clk_data() {
  uint8_t rv;

  sum_d = sum_c = 0;
  for( k=0; k<NAV; k++) {
    a = read_adc( ADC_DATA);
    sum_d += a;
    a = read_adc( ADC_CLK);
    sum_c += a;
  }

  rv = 0;
  if( (base_d - (sum_d / NAV)) >= THR)
    rv |= DATA_VAL;
  if( (base_c - (sum_c / NAV)) >= THR)
    rv |= CLK_VAL;

  return rv;
}

//
// wait for clock state change or button press
// return data state, set do_reset on button press
//
uint8_t wait_for_clock( uint8_t c)
{
  uint8_t s;

  do {
    s = sample_clk_data();
    if( bit_is_clear( SW_PIN, SW_BIT)) {
      do_reset = 1;
      return 0;
    }
  } while( (s & CLK_VAL) != c);

  return( (s & DATA_VAL) != 0);
}

// receive blinky byte
uint8_t rx_byte() {

  uint8_t bit, byte, d;
  uint8_t i;

  bit = 0x80;
  byte = 0;

  for( i=0; i<4; i++) {
    d = wait_for_clock( 1);
    if( do_reset) return 0;
    if( d)
      byte |= bit;
    bit >>= 1;
    d = wait_for_clock( 0);
    if( do_reset) return 0;
    if( d)
      byte |= bit;
    bit >>= 1;
  }
  
  //  led_flip( 0x80);		/* toggle LED8 */
  led_set( byte);
  
  return byte;
}

// receive an intel hex record into buffer
// return type or -1 on failure
int rx_ihex() {

  uint8_t* p = ihex;
  uint8_t i, n, c, s;

  n  = rx_byte();	/* get length */
  if( n == 0)		/* ignore length 0 records for now */
    return 0;

  ihex_nd = n;
  *p++ = n;

  for( i=0; i<3; i++) {
    *p++ = rx_byte();	/* get addr_hi, addr_lo, type */
    if( do_reset) return -2;
  }
  ihex_nd = ihex[IHEX_LEN];

  ihex_addr = (ihex[IHEX_ADDR] << 8) | ihex[IHEX_ADDR+1];
  if( ihex_nd > 0 && ihex_nd <= 0x10) {
    for( i=0; i<ihex_nd; i++) {
      *p++ = rx_byte();		/* get data */
      if( do_reset) return -2;
    }
  }
  c = rx_byte();		/* get checksum */
  *p++ = c;			/* store checksum at end */
  if( do_reset) return -2;
  // calculate sum of received bytes
  s = 0;
  for( i=0; i<(ihex_nd+4); i++)
    s += ihex[i];

  s = (s ^ 0xff)+1;
  *p++ = s;			/* store raw sum */

  if( c == s ) {
    return ihex[IHEX_TYPE];
  } else {
    return -1;
  }
}



// delay one column with code 0..15
// about 0.5 ms per unit
void delay_column( uint8_t d)
{
  if( d < 15)
    _delay_loop_2( d * 128);
  else
    _delay_ms( 500);
}

// display messages if any in EEPROM
// returns:
// 0 - no messages to display
// 1 - button pressed
//
int show_messages() {
  uint8_t i, t, n, j, speed, c;

  eep_nd = eeprom_read_byte( 0); /* get EEPROM data size */

  // display EEPROM buffer size on low LEDs, high one on
  led_set( (eep_nd&0x7f) | 0x80);
  _delay_ms( 500);
  // turn off all LEDs
  led_off( 0xff);
  _delay_ms( 500);

  if( eep_nd < 4 || eep_nd > EEBUFSIZ)
    return 0;

  // goto blinky mode until button pressed
  // copy data from the EEPROM
  eeprom_read_block( eebuf, (void *)1, eep_nd);

#ifdef USE_UART
  // dump eeprom buffer
  uart_putc('=');
  uart_hex2( eep_nd);
  crlf();
  for( i=0; i<eep_nd; i++) {
    uart_hex2( eebuf[i]);
    crlf();
  }
  uart_putc( '*');
  crlf();
#endif

  n = eebuf[2];		/* length of first message */
  speed = (eebuf[1] >> 2) & 15; /* speed code 0-15, 7=default */

  // loop until button is pressed
  while( bit_is_set( SW_PIN, SW_BIT) ) {

    // space between messages
    for( j=0; j<10; j++)
      delay_column( speed);

    // loop over message
    for( i=0; i<n; i++) {
#ifdef USE_UART
      uart_putc( 'd');
      uart_hex2( i);
      uart_putc( '=');
#endif
      // look up character
      t = eebuf[3+i] * FONT_WIDTH;
      if( t < sizeof(font_table)) {
	for( j=0; j<FONT_WIDTH; j++) {
	  c = pgm_read_byte(&(font_table[t+j]));
	  led_set( c);
#ifdef USE_UART
	  uart_hex2( c);
	  uart_putc( ' ');
#endif
	  delay_column( speed);
	}
      } else {		// invalid code probably a space
	// delay for three extra columns for space
#ifdef USE_UART
	uart_putc('S');
#endif
	delay_column( speed);
	delay_column( speed);
	delay_column( speed);
      }
      led_off( 0xff);
      delay_column( speed); /* two blank columns between characters */
      delay_column( speed);
#ifdef USE_UART
      crlf();
#endif
    }
  }

  // fall out if button pressed
  return 1;
}


int main(void)
{
  uint8_t i, j, n, c;
  uint8_t speed;
  uint8_t t;
  uint8_t nblk;

  ioinit();
  // test LEDs
  led_off( 0xff);
  _delay_ms( 100);
  led_on( 0xff);
  _delay_ms( 100);
  led_off( 0xff);  
  for( i=0; i<8; i++) {
    _delay_ms(100);
    led_on( 1<<i);
  }
  _delay_ms(100);
  led_off( 0xff);


  // Power-up:   check for EEPROM message and display it indefinitely until
  // the button is pressed
  i = show_messages();

  do_reset = 1;

  while( 1) {

    // see if button is pressed
    // if so, recalibrate threshold, reset bit counter
    if( bit_is_clear( SW_PIN, SW_BIT) || do_reset) {

#ifdef USE_UART
      uart_putc( 'R');
      crlf();
#endif
      led_set( 0x80);

      // measure background level
      sum_d = sum_c = 0;
      for( k=0; k<NAV; k++) {
	a = read_adc( ADC_DATA);
	sum_d += a;
	a = read_adc( ADC_CLK);
	sum_c += a;
	_delay_ms(1);
      }
      base_d = sum_d / NAV;
      base_c = sum_c / NAV;

      // now wait for button to be released, wait a while

      // loop while button is still pressed
      while( bit_is_clear( SW_PIN, SW_BIT))
	;

      _delay_ms( 1000);
      // turn off all LEDs
      led_off( 0xff);

      do_reset = 0;
      ihex_nd = 0;
      memset( eebuf, 0xab, EEBUFSIZ);
    } // if( button pressed)...

    // look for intel hex records
    eep_nd = 0;

    while( !do_reset) {

      t = rx_ihex();
      ++nblk;
      
      if( do_reset)
	break;

      if( t < 0) {		/* error blink */
	for( i=0; i<5; i++) {
	  led_set( 0xf);
	  _delay_ms(100);
	  led_set( 0);
	  _delay_ms(100);
	}
      }

      if( t == 0) {		/* end-of-file record */
#ifdef USE_EEPROM
	if( eep_nd) {
	  // copy EEPROM RAM buffer to EEPROM
	  eeprom_write_byte( (void *)0, eep_nd); /* first byte is size */
	  eeprom_write_block( eebuf, (void *)1, eep_nd); /* then the data */
	}
#endif	
	break;
      }

      if( t == 6) {		/* EEPROM message */
	i = ihex_addr + ihex[IHEX_LEN]; /* top address */
	// copy data to EEPROM buffer in RAM

	if( ihex_addr < 128 && i < EEBUFSIZ) {
	  memcpy( &eebuf[ihex_addr], &ihex[IHEX_DATA], ihex[IHEX_LEN]);
	  if( i > eep_nd)
	    eep_nd = i;
	}
      }

    }

    // display messages if any, wait for button press
    show_messages();

  }

}

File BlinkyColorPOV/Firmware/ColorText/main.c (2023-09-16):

/*
 * full-function color Blinky text display
 *
 * Power-up check for correctly-checksummed message in EEPROM
 * if not found, load default red "Hello" message
 * Display green on top LED if EEPROM checksum is good, else red
 *
 * convert message to global arrays of pixels and colors
 * display when back-and-forth motion is sensed on i2c accelerometer.
 *
 * If button pressed, download message using simplified blinky
 * DDR protocol based on original Wayne&Layne idea.
 */

#include <stdio.h>
#include <string.h>
#include <avr/io.h>
#include <avr/eeprom.h>

#include <util/delay.h>

#include "neopixel.h"
#include "adc.h"
#include "uart.h"
#include "download.h"
#include "i2c.h"

#include "display.h"

#include "button.h"

// #define DEBUG

// setup uart for 9600 baud output
FILE usart0_str = FDEV_SETUP_STREAM(USART0SendByte, NULL, _FDEV_SETUP_WRITE);

// reference download record and count for text message
extern uint8_t irec_nd;
extern code_t irec[BUFSIZ];

static uint16_t c, d;

// global arrays to hold pixelated message
#define MAX_PIXELS (MAX_MSG*6)
extern uint8_t g_pixels[MAX_PIXELS];
extern uint8_t g_colors[MAX_PIXELS];
extern uint8_t g_numpix;
static int8_t i_pix;

// delay before starting display in percent
#define FRONT_PORCH 80
// delay after end of display in percent
#define BACK_PORCH 120

static int8_t rc;
static int8_t n;

// buffers for funky i2c function
static uint8_t abuf[1];
static uint8_t dbuf[1];
static uint8_t rbuf[3];

// deal with 32-bit non-interrupt driven timer at 120uS tick rate
static uint16_t tyme_lo;
static uint16_t tyme_hi;
#define TIME32 (((uint32_t)tyme_hi<<16)|((uint32_t)tyme_lo))

static uint32_t tyme_accel;
static uint32_t trig_tyme;
static uint32_t last_trig;

#define ACCEL_DELAY 78

// history of accel readings with timestamps
#define NPTS 10
static int8_t pts[NPTS];
static uint32_t times[NPTS];

int32_t x;
uint8_t left;
uint8_t tick;

// two of these hold the most recent sweep of the gizmo
// and the one before that
typedef struct {
  uint32_t pixel_first;		// time in sweep to start message
  uint16_t pixel_period;	// period between pixel columns
  int8_t dir;			// direction +/-1
  uint8_t valid;		// 1 if valid
} pixel_info_t;

// other variables used in calculating pixel display
uint32_t pixel_next;
uint32_t pixel_last;
uint16_t pixel_tick;
uint8_t pixel_idx;
uint8_t pixel_count;
int8_t pixel_dir;
uint8_t alive;

static pixel_info_t pix[2];
static pixel_info_t *pp;
static uint8_t active_pix;

// turn off all LEDs
#define blank() set_all(0,0,0)

// set selected LED only, others blank, update all
void set_one( uint8_t n, uint8_t r, uint8_t g, uint8_t b) {
  uint8_t i;
  for( i=0; i<8; i++) {
    if( i == n)
      sendPixel( r, g, b);
    else
      sendPixel( 0, 0, 0);
  }
  show();
}

// set all LEDs to same color
void set_all( uint8_t r, uint8_t g, uint8_t b) {
  sendPixel( r, g, b);
  sendPixel( r, g, b);
  sendPixel( r, g, b);
  sendPixel( r, g, b);
  sendPixel( r, g, b);
  sendPixel( r, g, b);
  sendPixel( r, g, b);
  sendPixel( r, g, b);
  show();
}

// update only first LED (for speed)
void setfirst( uint8_t r, uint8_t g, uint8_t b) {
  sendPixel( g, r, b);
  show();
}  

int main (void)
{
  uint8_t i;

  ledsetup();
  InitADC();
  USART0Init();
  BUTTON_PORT |= (1<<BUTTON_BIT);
  i2c_init( BDIV);

  stdout = &usart0_str;
  _delay_ms(10);
  blank();

  // setup timer 1 to wrap every 120us, no interrupts
  TCCR1A = 0;
  TCCR1B = 0x05;		/* mode 0, prescale 1024 */

  // write 1 to accelerometer mode register to turn it on
  abuf[0] = 7;
  dbuf[0] = 1;
  rc = i2c_io( ACC_I2C_ADR, abuf, 1, dbuf, 1, NULL, 0);
#ifdef DEBUG
  if( rc) printf("I2C err=%d\n", rc);
#endif
  // set address for subsequent I2C reads
#ifdef PCB_REV3
  abuf[0] = 1;
#else  
  abuf[0] = 0;
#endif
  
  // power-up LED test, chase white LED
  blank();
  for( i=0; i<8; i++) {
    set_one( i, 20, 20, 20);
    _delay_ms(100);
  }
  blank();
  setfirst( 10, 0, 0);

  // try to read message from eeprom
  eeprom_read_block( irec, 0, sizeof(irec));
  if( check_sum()) {
    setfirst( 10, 0, 0);	// first LED red if fail
    // preload with "Hello" message
    defmsg();
  } else {
    setfirst( 0, 10, 0);	// first LED green if OK
    irec_nd = irec[IREC_LEN];
  }

  _delay_ms(100);

#ifdef DEBUG
  printf("Hello\n");
  printf("rec len=%d\n", irec_nd);
#endif
  // convert message to pixels
  msg_to_pixels();
  TCNT1 = 0;			// reset timer
  tyme_accel = TCNT1;

#ifdef DEBUG
  printf("numpix = %d\n", g_numpix);
#endif

  while( 1) {			// ----------main loop -----------

    if( button_pressed()) {	// button press -- download message
      _delay_ms( 500);
      setfirst( 10, 10, 0);
      calibrate();		// set black level
      setfirst( 0, 10, 10);
      rc = rx_irec();		// receive blinky record, return if
                                // button pressed
      if( rc) {
	setfirst( 10, 0, 0);	// checksum error in download
      } else {
	eeprom_write_block( irec, 0, sizeof(irec));
	setfirst( 0, 10, 0);	// checksum good
	msg_to_pixels();
      }
      _delay_ms(100);
      TCNT1 = 0;		// reset timer to start display
      tyme_lo = tyme_hi = 0;
    }


    // wait for timer tick, every 120uS
    while( tyme_lo == TCNT1)
      ;
    if( TCNT1 < tyme_lo)	// update upper 16 bits
      ++tyme_hi;
    tyme_lo = TCNT1;

    // see if time for accelerometer update
    // every 10ms
    if( TIME32 - tyme_accel > ACCEL_DELAY) {
      tyme_accel = TIME32;

      // read accelerometer
      rc = i2c_io( ACC_I2C_ADR, abuf, 1, NULL, 0, rbuf, 3);
#ifdef DEBUG
      if( rc) printf("I2C err=%d\n", rc);
#endif
      if( !(rbuf[0] & 0x40)) {	// check for read/write collision
	// convert acceleration to signed number
	int8_t v = (rbuf[0] & 0x3f) << 2;
	v /= 4;

	// keep history of NPTS points with timestamps
	memmove( pts, pts+1, NPTS-1);
	pts[NPTS-1] = v;

	memmove( &times[0], &times[1], sizeof(times[0])*NPTS-1);
	times[NPTS-1] = TIME32;

	// check for zero-crossing positive-going
	if( pts[0] < 0 && pts[1] < 0 && pts[2] < 0 &&
	    pts[NPTS-1] > 0 && pts[NPTS-2] > 0 && pts[NPTS-3] > 0 && !left && !tick) {
	  // trigger on left-going sweep
	  left = 1;
	  last_trig = trig_tyme;
	  trig_tyme = times[NPTS/2];
	  tick = 1;
	} else if( pts[0] > 0 && pts[1] > 0 && pts[2] > 0 &&
		   pts[NPTS-1] < 0 && pts[NPTS-2] < 0 && pts[NPTS-3] < 0 && left && !tick) {
	  // trigger on right-going sweep
	  left = 0;
	  last_trig = trig_tyme;
	  trig_tyme = times[NPTS/2]; // approx. time of zero crossing
	  tick = 1;
	}
      }	// valid I2C data

      // this macro gives the time in 120uS ticks since last trigger
#define TrigDelay (trig_tyme-last_trig)
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
